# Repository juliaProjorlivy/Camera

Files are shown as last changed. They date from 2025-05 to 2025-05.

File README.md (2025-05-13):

# Camera project

Идея проекта заключалась в том, чтобы создать камеру, реагирующую на движение. В итоговом варианте камера реагирует на синий цвет, а также может двигаться с помощью пульта. Мозгом нашего проекта стала [Raspberry pi 4](https://www.raspberrypi.com/documentation/computers/raspberry-pi.html) с камерой [Camera Module 3.](https://www.raspberrypi.com/products/camera-module-3/)  Чтобы камера была подвижной по осям Ox и Oy, мы использовали два [сервопривода](https://docs.sunfounder.com/projects/ultimate-sensor-kit/en/latest/components_basic/27-component_servo.html). Для включения/выключения камеры и её управления был задействован [ИК-приемник,](https://roboshop.spb.ru/sensors/infrakrasnye-datchiki/tl1838), управляемый [Arduino Nano](https://3d-diy.ru/blog/arduino-nano/?srsltid=AfmBOoobsfLvRHXmztk4oDekqijM6OquVmeA1C7HS3Jm3zs6FXj-3EUY).

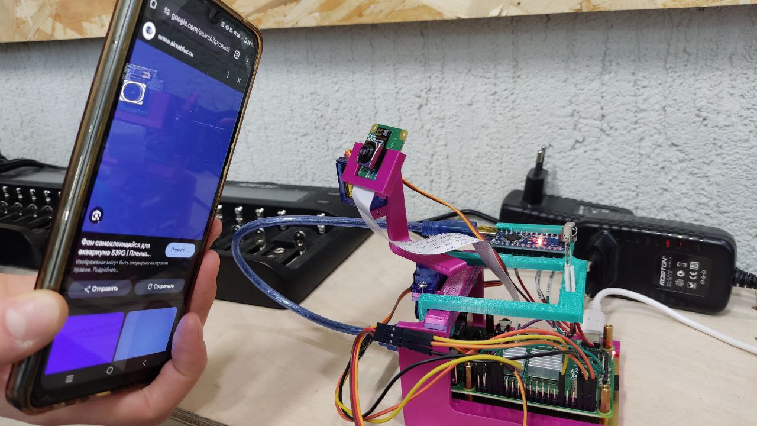
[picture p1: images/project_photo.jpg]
project_image


project_gif

# Настройка Raspberry pi

## Установка OS и VNC

Накатили Raspberry pi OS (все необходимое можно найти
[здесь](https://www.raspberrypi.com/software/)).
Советую сразу настроить удаленный доступ к графическому интерфейсу
[VNC для удобной работы с малинкой.](https://habr.com/ru/sandbox/148360/)

## Настройка виртуального окружения для работы с python

Для нормальной работы с библиотекой picamra2 лучше установить виртуальное окружение:

```sh
sudo apt install python3-venv
python3 -m venv —system-site-packages env
```

Для активации:

```sh
source env/bin/activate
```

Соответственно, чтобы выйти из окружения: `deactivate`.  
Для работы с пинами малинки использовали библиотеку [pigpio](https://abyz.me.uk/rpi/pigpio/pigpiod.html), для работы с которой нужно запустить pigpio library as a daemon:

```sh
sudo pigpiod
```

## Настройка ИК-приемника

## ИК-приемник на Raspberry pi (LIRC)

Вообще говоря, сначала мы пытались обрабатывать кнопки всё так же на малинке через библиотеку LIRC. Нужно было немного изменить конфиг малинки, добавив несколько строчек в него ([вот здесь всё детально расписано](https://www.instructables.com/Setup-IR-Remote-Control-Using-LIRC-for-the-Raspber/)).

Схему подключения ИК-приёмника к малинке не буду вставлять — тут всё просто: GND к GND, VCC к 3.3V, OUT к, например, 18 порту малинки (GPIO18 имеет альтернативную функцию **PCM_CLK**, которая позволяет использовать аппаратный PWM, что критично для стабильного декодирования ИК-сигналов).

Проверяем, что ИК-приёмник работает:

```sh
mode2 -d /dev/lirc0
```

Если на экран выводится **pulse/space codes**, то всё круто — работает.
Второй шаг — найти конфиг для нашего пульта. У нас это обычный китайский пульт Car MP3.

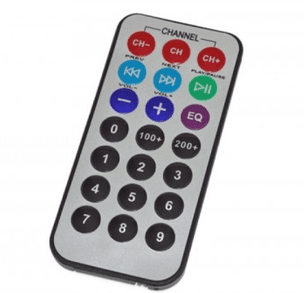
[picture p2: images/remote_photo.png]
remote_image


Но внимание! В общем [архиве](https://lirc.sourceforge.net/remotes/) не нашлось конфига! Однако мы не отчаялись. В таком случае можно вручную записать свой конфиг, используя утилиту irrecord. Как и было написано в указанной ранее [статье](https://www.instructables.com/Easy-Setup-IR-Remote-Control-Using-LIRC-for-the-Ra/): "I was VERY unsuccessful trying to create a file using this utility despite much effort".
Разочаровавшись, мы пошли вглубь интернета с целью всё-таки найти конфиг под наш пульт. Если кому-то понадобится, ссылка есть на [этом сайте](https://elchupanibrei.livejournal.com/43594.html) рядом с изображением пульта.
Добавляем наш конфиг в `/etc/lirc/lircd.conf.d/` и включаем его в `/etc/lirc/lircd.conf`:

```sh
mv carMP3.conf /etc/lirc/lircd.conf.d/
sudo echo 'include "lircd.conf.d/*.conf"' >> /etc/lirc/lircd.conf 
```

Перезапускаем LIRC и проверяем работает ли конфиг для пульта:

```sh
sudo service lirc start
irw /var/run/lirc/lircd
```

После нажатия на кнопку пульта должно выводиться что-то типа:

```sh
0000000000ffb04f 00 KEY_200+ carMP3.conf
```

Проделываем те же махинации, что и в статье, за исключением содержания irexec.lircrc — его делаем своим. Итак, после перезапуска малинки кнопка пульта должна была выполнить указанные в irexec.lircrc команды, но ничего опять не получилось. Я даже проверяла логи:

```sh
sudo journalctl -u lircd -n 50 --no-pager
```

Но ошибки, вроде бы, и не было, однако ничего не работало как надо. Поэтому было принято стратегическое решение воспользоваться Arduino для работы с пультом — так оказалось в разы проще.

## ИК-приемник и arduino nano

Итак, перед нами цель — сделать так, чтобы Arduino принимала сигналы с ИК-приёмника и отправляла название кнопки через Serial-порт на малинку.
Готовый скетч для этого уже есть в интернете: [https://newbiely.com/tutorials/arduino-nano/arduino-nano-ir-remote-control](https://newbiely.com/tutorials/arduino-nano/arduino-nano-ir-remote-control). Я его впоследствии немного адаптировала под свои нужды (об этом подробнее позже).
Краткий алгоритм действий:

1. Загружаем скетч на Arduino
2. Проверяем через Serial Monitor корректность отображения нажатий кнопок пульта
3. Подключаем собранную схему к Raspberry Pi (не забываем про USB-кабель)

circuit_image

## Написание кода

### Код для камеры и сервоприводов

В изначальном варианте мы хотели использовать YOLO как модель компьютерного зрения для обнаружения объектов (в частности, людей). Однако малинка работала исключительно медленно, поэтому мы отказались от этой идеи. Вместо этого наша камера детектит объекты синего цвета и, соответственно, движется в их сторону. Для анализа изображений мы используем библиотеку OpenCV. Код с YOLO и наш код лежат в исходниках.

### Как arduino взаимодействует с Raspberry pi

Внутри основной программы создаются два потока выполнения:

1. Первый поток отвечает за:
   - Обработку изображений с камеры
   - Поиск координат центра обнаруженного объекта
   - Управление сервоприводами
2. Второй поток выполняет:
   - Ожидание сигналов через Serial-порт от Arduino
   - Обработку нажатий кнопок пульта

Взаимодействие между потоками организовано через очередь сообщений. Исходный код доступен в файле `src/arduino.py`.

### Запись видео

Для добавления функциональности записи видео мы использовали примеры из официального репозитория [picamera2](https://github.com/raspberrypi/picamera2/tree/main). В частности, был взят за основу скрипт [capture_video.py](https://github.com/raspberrypi/picamera2/blob/main/examples/capture_video.py) и интегрирован в наш проект.

1. Поскольку при настройке автозапуска мы использовали команду `sudo crontab -e` вместо `crontab -e`, все прописанные инструкции выполнялись с правами root.

> На компьютере обычно имеются общесистемный файл ( /etc/crontab ), и индивидуальные файлы ( /var/cron/tabs/<имя-пользователя> ) для пользователей системы. Таким образом, команды в файле будут выполняться с правами этих пользователей ...

Поэтому для сохранения видеофайла необходимо указывать полный путь.

2. Включение/выключение записи мы хотели привязать к определённым кнопкам пульта.

```python
# Some code before
elif((command == "0") and not IS_RECORDING):
    IS_RECORDING = True
    filename = f"/home/pi/images/record_{datetime.now().strftime('%Y%m%d_%H%M%S')}.h264"
    picam2.start_recording(encoder, filename)
elif(command == "1" and IS_RECORDING):
    IS_RECORDING = False
    picam2.stop_recording()
```

Но здесь возникла проблема. По всей видимости, `picam2.stop_recording()` полностью выключает камеру. Вот цитата из мануала:

> We also used the convenient start_recording and stop_recording functions, which start and stop both the encoder and the
camera together. Sometimes it can be useful to separate these two operations, for example you might want to start and
stop a recording multiple times while leaving the camera running throughout. For this reason, start_recording could have
been replaced by:

```python
encoder.output = 'test.h264'
picam2.start_encoder(encoder)
picam2.start()
```

> and stop_recording by:

```python
picam2.stop()
picam2.stop_encoder()
```

В таком случае я попыталась использовать `picam2.stop_encoder()` и `picam2.start_encoder()`, но код всё равно не работал. Поэтому я просто добавила `picam2.start()` после `picam2.stop_recording()` — и код заработал.

## Включение камеры по пульту

Теперь необходимо реализовать включение камеры (запуск Python-скрипта) по нажатию кнопки на пульте. Для этого мы можем использовать следующий подход:

1. Arduino при старте подаёт высокий сигнал на определённый GPIO-пин
   - Для этого потребуется модификация существующего скетча
2. Raspberry Pi должен:
   - Детектировать этот сигнал через GPIO
   - Запускать основной Python-скрипт обработки

Основные технические сложности реализации:

1. Требуется дополнительный скрипт, который должен:
   - Автозапускаться при включении Raspberry Pi
   - Ожидать сигнал на GPIO-пине
2. Необходима автоматическая активация демона pigpiod при старте системы:
   - Для корректной работы библиотеки pigpio

Это все довольно легко решается с помощью [Cron](https://timeweb.com/ru/community/articles/chto-takoe-cron).

```sh
sudo crontab -e
```

Добавляем следующую строчку в конец и перезапускаемся:

```sh
@reboot /home/pi/env/bin/python3 /home/pi/listener.py > log_listener.txt 2>&1
```

где listener.py - скрипт, ожидающий сигнала. Теперь при включении малинки, запускается listener.py на заднем фоне.  Это можно проверить командой:

```sh
ps aux | grep python
```

При получении сигнала listener.py запускает еще один скрипт - awake.sh, который лишь запускает демона pigpio и основную прогу.

# Создание корпуса и работа с 3D принтером

Главной задачей было обеспечить подвижность камеры во всех направлениях и добиться органичного расположения всех компонент сборки в пространстве. За счёт отсутствия некоторых особенностей камеры и raspberry pi в 3D моделях из интернета, некоторые измерения были произведены вручную и отражены на 3D деталях, что приводило к неточностям в сборке. В итоге, благодаря клею и напильникам, все вылившиеся в физической форме недочёты были устранены и отлажены под оборудование.

Главной проблемой была разработка надёжного сцепления крепежа и деталей, т. к. винты, предназначенные для сервоприводов и камеры, либо отсутствовали, либо не соответствовали нашим требованиям (ненадёжно вкручивались в пластик за счёт своей малой длины). Эта проблема была решена за счёт подбора размеров и форм 3D деталей, обеспечивающих большую площадь соприкосновения и удерживающих конструкцию с помощью силы трения.

Итоговая конструкция позволяет реализовывать все запрограммированные функции системы и обеспечивает надёжную связку и свободную эксплуатацию всех компонент.

# Перспективы развития и возможные улучшения

Несмотря на работоспособность текущего решения, эти доработки помогут сделать систему более удобной и надежной:

## 1. Заменить использование Cron на systemd для автозапуска скрипта.
И вот почему:
   - Cron запускает задачи строго по расписанию, даже если система не готова (например, сеть не поднята, сервисы не инициализированы). В то время как systemd может ждать завершения загрузки (After=network.target), монтирования дисков или других сервисов, что критично для скриптов, зависящих от окружения.
   - Если процесс упадёт, Cron он не перезапустится. Systemd может перезапускать упавшие процессы (Restart=on-failure), логировать вывод (StandardOutput=journal) и отслеживать их состояние.
   - Cron требует указания пользователя (@reboot pi /path/to/script), а systemd может работать как системный сервис.
Можно добавить файл `/etc/systemd/system/my_script.service` с содержанием:

```sh
[Unit]
Description=My Custom Camera Startup Script
After=network.target

[Service]
ExecStart=/home/pi/env/bin/python3 /home/pi/listener.py
Restart=on-failure
User=pi

[Install]
WantedBy=multi-user.target
```

и активировать его:

```sh
sudo systemctl enable my_script
sudo systemctl start my_script
```

## 2. Исправить шатание камеры
На данном этапе код работает нормально, однако существуют некоторые нюансы. При тестировании устройства мы заметили, что иногда камера начинает шататься из стороны в сторону, хотя синий объект остается неподвижным.

Проанализировав явление, я пришла к выводу, что причиной был свет, отраженный от гладкой поверхности синего пластика. Дело в том, что менялся оттенок синего.
Под капотом (в коде) камера ищет контуры синего цвета, определяет наибольший контур и центрируется относительно него.
То есть из-за бликов оттенок синего постоянно меняется, поэтому один большой синий контур разбивается на несколько. Из-за этого камера начинает "елозить".
Поэтому в планах — придумать решение описанной проблемы.

## 3. Обработка ошибок при нажатии на кнопку пульта
У Arduino не всегда получается распознать кнопку пульта с первого раза (выводится "undefined command"), что особенно критично для:

- Кнопки включения/выключения
- Кнопки запуска/остановки записи видео

В качестве решения предлагается добавить светодиодный индикатор, который будет визуально подтверждать:

 1. Факт приёма сигнала от пульта
 2. Корректность распознавания команды
 3. Текущий статус выполнения (например, мигание при обработке)

## 4. Обработать двойное нажатия кнопки запуска камеры
При включении Raspberry Pi запускается скрипт `listener.py`, ожидающий сигналов с пульта. При обнаружении нужного сигнала запускается основная программа. Однако при повторном нажатии на ту же кнопку (когда программа уже запущена) возникают конфликты.

Дело в том, что `listener.py` запускает ещё один процесс с этой программой, обращающийся к тем же Serial-портам. Это приводит к зависанию обоих запущенных процессов.

В качестве решения проблемы я добавила в `listener.py` проверку на то, что программа уже запущена. Если это так, то нажатие кнопки игнорируется. Однако при таком подходе приходится перебирать все запущенные программы в цикле и искать нужную по имени.

На эти операции уходит много времени, и задержка становится заметной для пользователя. Поэтому в планах — придумать более элегантное решение, которое не требовало бы таких временных затрат.

## 5. Использование оставшихся кнопок пульта
В текущей реализации остаются незадействованные кнопки пульта, которые можно использовать для новых функций. Например, можно устанавливать цвет, который необходимо отслеживать.

## 6. Поиск человека
Возвращение к изначальной цели — реакции на движение человека. Скорее всего, существуют способы улучшения производительности при использовании модели на Raspberry Pi. Например, передача данных напрямую по DMA, снимая нагрузку с CPU.

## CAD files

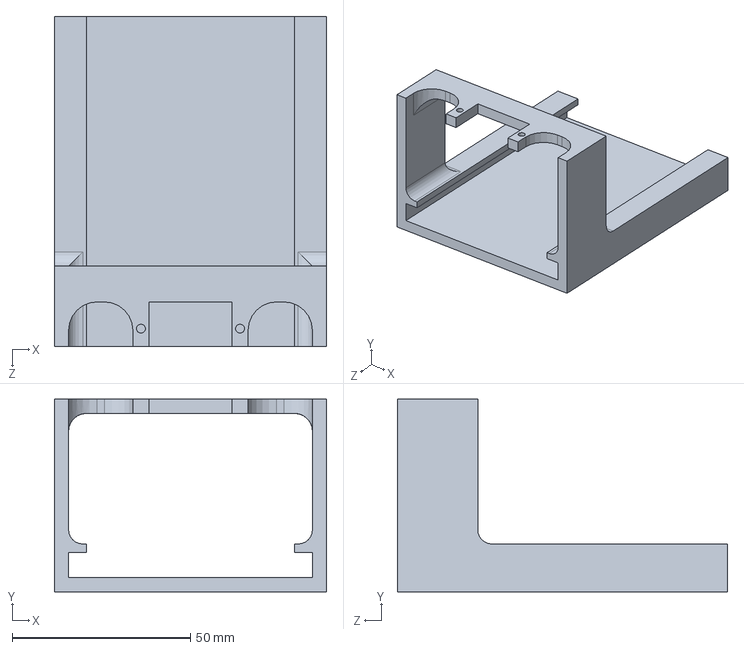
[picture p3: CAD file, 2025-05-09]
3d_models/main_holder.SLDPRT
76.4 x 54.0 x 92.5 mm

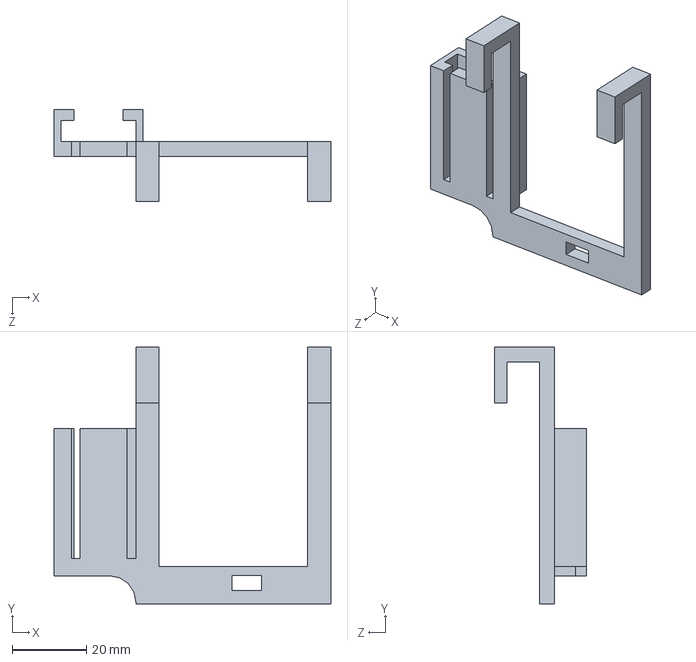
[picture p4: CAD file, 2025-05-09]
3d_models/ардуинодержатель.SLDPRT
74.5 x 69.0 x 24.8 mm

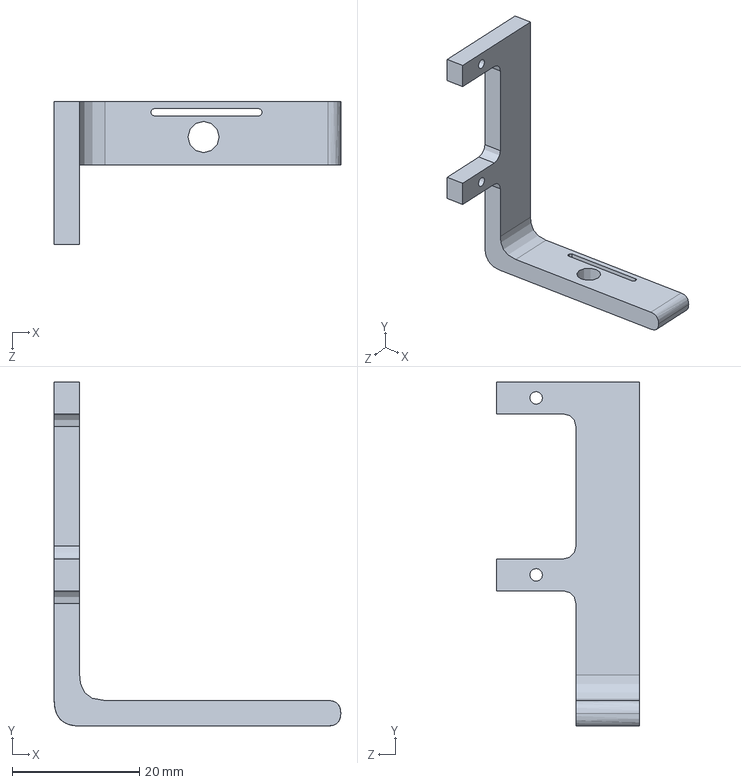
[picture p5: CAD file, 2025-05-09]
3d_models/camera_holder1.SLDPRT
45.0 x 54.0 x 22.5 mm

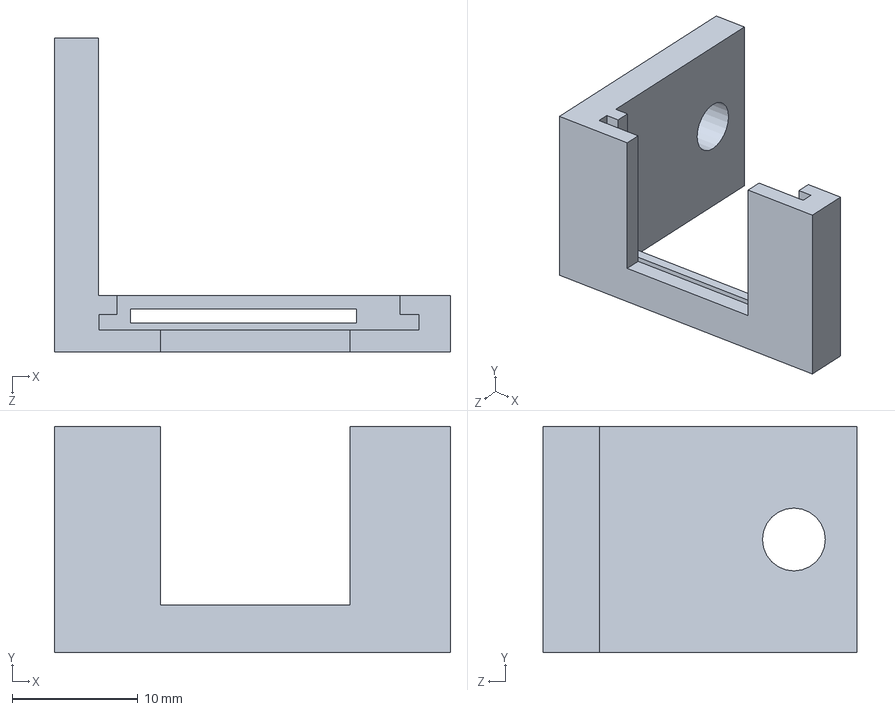
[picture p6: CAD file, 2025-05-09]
3d_models/near_camera1.SLDPRT
31.5 x 18.0 x 25.0 mm

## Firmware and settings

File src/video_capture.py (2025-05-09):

from picamera2 import Picamera2, Preview
import cv2
import numpy as np
import time
import pigpio
import threading
import serial
from queue import Queue
from datetime import datetime
from picamera2.encoders import H264Encoder
import os

# =============================================
# Shared Data Queue (Thread-Safe)
# =============================================
data_queue = Queue()

# =============================================
# Serial Reader Thread
# =============================================
def serial_reader(shutdown_event, thread_returned):
    ser = serial.Serial('/dev/ttyUSB0', 9600)
    print("Serial reader thread started")
    try:
        while not shutdown_event.is_set():
            if ser.in_waiting > 0:
                line = ser.readline().decode().strip()
                print(f"Received from Arduino serial reader: {line}")
                data_queue.put(line)  # Send to main thread
                if(line == "CH"):
                    thread_returned.set()
                    return
    except Exception as e:
        print(f"Serial reader error {e}")
    finally:
        print("closing serial port ttyUSB0")
        ser.close()

# =============================================
# Servo Controller Class
# =============================================
SCREEN_WIDTH = 640
SCREEN_HEIGHT = 480
SERVO_MIN_PULSE = 500
SERVO_MAX_PULSE = 2500
SERVO_RANGE = 180

class ServoController:
    def __init__(self, pin_x, pin_y):
        self.pin_x = pin_x
        self.pin_y = pin_y
        self.current_angle_x = -1
        self.current_angle_y = -1
        self.DEADZONE = 5.0  # Degrees

        # Initialize pigpio
        self.pi = pigpio.pi()
        if not self.pi.connected:
            raise RuntimeError("Failed to connect to pigpio daemon")

        self.set_angle(90, 90)  # Center position

    def map_to_pulse(self, angle):
        return SERVO_MIN_PULSE + (angle * (SERVO_MAX_PULSE - SERVO_MIN_PULSE) // SERVO_RANGE)

    def set_angle(self, angle_x, angle_y):
        # Only move if outside deadzone
        if (abs(angle_x - self.current_angle_x) > self.DEADZONE or 
            abs(angle_y - self.current_angle_y) > self.DEADZONE):

            # Apply constrained angles
            angle_x = max(0.0, min(float(SERVO_RANGE), angle_x))
            angle_y = max(0.0, min(float(SERVO_RANGE), angle_y))

            # Update servos
            if angle_x != self.current_angle_x:
                self.pi.set_servo_pulsewidth(self.pin_x, self.map_to_pulse(angle_x))
                self.current_angle_x = angle_x
            if angle_y != self.current_angle_y:
                self.pi.set_servo_pulsewidth(self.pin_y, self.map_to_pulse(angle_y))
                self.current_angle_y = angle_y

    def update_from_coordinates(self, x, y):
        # Convert screen coordinates to servo angles
        angle_x =self.current_angle_x - ((x - SCREEN_WIDTH/2) * 20) / SCREEN_WIDTH
        angle_y =self.current_angle_y + ((y - SCREEN_HEIGHT/2) * 20) / SCREEN_HEIGHT
        self.set_angle(angle_x, angle_y)

    def move_to(self, x, y):
        angle_x = self.current_angle_x + x
        angle_y = self.current_angle_y + y
        self.set_angle(angle_x, angle_y)

    def cleanup(self):
        self.pi.stop()

# =============================================
# Main Tracking Thread
# =============================================
def object_tracker(shutdown_event, thread_returned):
   # Initialize camera with optimized settings
    picam2 = Picamera2()

    # Camera configuration
    config = picam2.create_preview_configuration(
        main={"size": (640, 480)},
        controls={"FrameRate": 60}
    )
    picam2.configure(config)
    encoder = H264Encoder(10000000)

    # To control video recording
    IS_RECORDING = False
    # Initialize servo controller (GPIO pins for X and Y servos)
    try:
        servos = ServoController(18, 12)
    except RuntimeError as e:
        print(f"Servo initialization failed: {e}")
        exit(1)

    # Red color range in HSV (two ranges for red)
    lower_red1 = np.array([0, 120, 70])    # Lower range for red (0-10)
    upper_red1 = np.array([10, 255, 255])
    lower_red2 = np.array([170, 120, 70])  # Upper range for red (170-180)
    upper_red2 = np.array([180, 255, 255])

    # Jitter reduction parameters
    min_contour_area = 500  # Minimum size to consider as valid object

    # Morphological kernel for noise reduction
    kernel = np.ones((5,5), np.uint8)

    try:
        picam2.start()
        while not shutdown_event.is_set():
            # Process any incoming serial commands
            if not data_queue.empty():
                command = data_queue.get()
                print(f"Processing command from camera: {command}")
                if(command == ">>"):
                    servos.move_to(20, 0)
                elif(command == "<<"):
                    servos.move_to(-20, 0)
                elif(command == "+"):
                    print("moving up")
                    servos.move_to(0, -20)
                elif(command == "–"):
                    print("moving down")
                    servos.move_to(0, 20)
                elif(command == "EQ"):
                    print("moving center")
                    servos.set_angle(90, 90)
                elif(command == "CH"):
                    thread_returned.set()
                    return
                elif((command == "0") and not IS_RECORDING):
                    IS_RECORDING = True
                    filename = f"/home/pi/images/record_{datetime.now().strftime('%Y%m%d_%H%M%S')}.h264"
                    try:
                        picam2.start_recording(encoder, filename)
                    except Exception as ex:
                        template = "An exception of type {0} occurred. Arguments:\n{1!r}"
                        message = template.format(type(ex).__name__, ex.args)
                        print(f"in except\n {message}")
                elif(command == "1" and IS_RECORDING):
                    IS_RECORDING = False
                    picam2.stop_recording()
                    picam2.start()
                    print("Recording finished.")

            frame = picam2.capture_array()
            # Convert from RGB to HSV color space
            hsv = cv2.cvtColor(frame, cv2.COLOR_BGR2HSV)

            # Create masks for blue color (two ranges)
            mask1 = cv2.inRange(hsv, lower_red1, upper_red1)
            mask2 = cv2.inRange(hsv, lower_red2, upper_red2)
            mask = cv2.bitwise_or(mask1, mask2)

            # Noise reduction
            mask = cv2.morphologyEx(mask, cv2.MORPH_OPEN, kernel)
            mask = cv2.morphologyEx(mask, cv2.MORPH_CLOSE, kernel)

            # Find contours in the mask
            contours, _ = cv2.findContours(
                mask, 
                cv2.RETR_EXTERNAL,
                cv2.CHAIN_APPROX_SIMPLE
            )

            if contours:
                # Find largest contour
                largest_contour = max(contours, key=cv2.contourArea)

                # Only proceed if contour is large enough
                if cv2.contourArea(largest_contour) > min_contour_area:
                    x, y, w, h = cv2.boundingRect(largest_contour)
                    center_x = x + w // 2
                    center_y = y + h // 2  # Fixed: removed incorrect subtraction
                    print(f"Tracking at: {center_x}, {center_y}")

                    # Update servos with smoothed coordinates
                    servos.update_from_coordinates(center_x, center_y)
            # Exit on 'q' key press
            if cv2.waitKey(1) & 0xFF == ord('q') or shutdown_event.is_set():
                break
    finally:
        if IS_RECORDING:
            picam2.stop_recording()
            print("Recording finished.")
        picam2.stop()
        picam2.close()
        servos.cleanup()
        print("closing picam2 and servos")


# =============================================
# Main Program
# =============================================
if __name__ == "__main__":
    shutdown_event = threading.Event()
    thread_returned = threading.Event()
    # Start threads
    serial_thread = threading.Thread(target=serial_reader, args=(shutdown_event,thread_returned,))
    tracker_thread = threading.Thread(target=object_tracker, args=(shutdown_event,thread_returned,))

    serial_thread.start()
    tracker_thread.start()

    # Keep main thread alive
    try:
        while not thread_returned.is_set():
            time.sleep(1)
    except KeyboardInterrupt:
        print("\nShutting down...")
    finally:
        shutdown_event.set()
        serial_thread.join()
        tracker_thread.join()
        if serial_thread.is_alive():
            print("Failed to close the serial thread properly")
        if tracker_thread.is_alive():
            print("Failed to close the tracker thread properly")

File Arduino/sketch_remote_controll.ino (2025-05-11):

#include <DIYables_IRcontroller.h> // DIYables_IRcontroller library
#define IR_RECEIVER_PIN 7 // The Arduino pin connected to IR controller
#define SIGNAl_PORT 10 // The Arduino pin connected to Raspberry pi 16 pin (to control turning on)

DIYables_IRcontroller_21 irController(IR_RECEIVER_PIN, 200); // debounce time is 200ms

void setup() {
  pinMode(SIGNAL_PORT, OUTPUT);
  Serial.begin(9600);
  irController.begin();
}

void loop() {
  Key21 command = irController.getKey();
  if (command != Key21::NONE) {
    switch (command) {
      case Key21::KEY_CH_MINUS:
        Serial.println("CH-");
        digitalWrite(SIGNAL_PORT, HIGH);    // turn the LED on by making the voltage HIGH
        delay(1000);                       // wait for a second
        digitalWrite(LED_BUILTIN, LOW);    // turn the LED off by making the voltage LOW
        // TODO: YOUR CONTROL
        break;

      case Key21::KEY_CH:
        Serial.println("CH");
        // TODO: YOUR CONTROL
        break;

      case Key21::KEY_CH_PLUS:
        Serial.println("CH+");
        // TODO: YOUR CONTROL
        break;

      case Key21::KEY_PREV:
        Serial.println("<<");
        // TODO: YOUR CONTROL
        break;

      case Key21::KEY_NEXT:
        Serial.println(">>");
        // TODO: YOUR CONTROL
        break;

      case Key21::KEY_PLAY_PAUSE:
        Serial.println(">||");
        // TODO: YOUR CONTROL
        break;

      case Key21::KEY_VOL_MINUS:
        Serial.println("–");
        // TODO: YOUR CONTROL
        break;

      case Key21::KEY_VOL_PLUS:
        Serial.println("+");
        // TODO: YOUR CONTROL
        break;

      case Key21::KEY_EQ:
        Serial.println("EQ");
        // TODO: YOUR CONTROL
        break;

      case Key21::KEY_100_PLUS:
        Serial.println("100+");
        // TODO: YOUR CONTROL
        break;

      case Key21::KEY_200_PLUS:
        Serial.println("200+");
        // TODO: YOUR CONTROL
        break;

      case Key21::KEY_0:
        Serial.println("0");
        // TODO: YOUR CONTROL
        break;

      case Key21::KEY_1:
        Serial.println("1");
        // TODO: YOUR CONTROL
        break;

      case Key21::KEY_2:
        Serial.println("2");
        // TODO: YOUR CONTROL
        break;

      case Key21::KEY_3:
        Serial.println("3");
        // TODO: YOUR CONTROL
        break;

      case Key21::KEY_4:
        Serial.println("4");
        // TODO: YOUR CONTROL
        break;

      case Key21::KEY_5:
        Serial.println("5");
        // TODO: YOUR CONTROL
        break;

      case Key21::KEY_6:
        Serial.println("6");
        // TODO: YOUR CONTROL
        break;

      case Key21::KEY_7:
        Serial.println("7");
        // TODO: YOUR CONTROL
        break;

      case Key21::KEY_8:
        Serial.println("8");
        // TODO: YOUR CONTROL
        break;

      case Key21::KEY_9:
        Serial.println("9");
        // TODO: YOUR CONTROL
        break;

      default:
        Serial.println("WARNING: undefined command:");
        break;
    }
  }
}

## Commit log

2025-05-09 added 3d models and clean up
    [camera_holder1.SLDPRT, main_holder.SLDPRT, near_camera1.SLDPRT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]
2025-05-11 added arduino sketch and changed readme
